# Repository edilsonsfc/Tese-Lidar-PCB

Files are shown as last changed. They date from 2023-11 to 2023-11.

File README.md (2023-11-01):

# Circuit Board (PCB) of Master's Thesis
This repository contains the circuit board project and supplementary materials related to my master's thesis.

## Table of Contents
- [Introduction](#introduction)
- [PCB](#pcb)
- [How to Use](#how-to-use)
- [Citation](#citation)

## Introduction
My master's thesis, titled "Three-dimensional mapping of an unknown environment based on a 2D laser measurement" explores the development of a low-cost 3D mapping system capable of generating a point cloud of an indoor environment and performing path planning. The work presented in this repository supports the findings and experiments conducted during the research process.
- [Hardware Structure](https://github.com/edilsonsfc/Tese-Lidar-Structure)
- [Printed Circuit Board](https://github.com/edilsonsfc/Tese-Lidar-PCB)
- [Control and Data Processing Algorithm](https://github.com/edilsonsfc/Tese-Lidar-Code)
- [Graphical User Interface](https://github.com/edilsonsfc/Tese-Lidar-GUI)

## PCB
This repository contains a collection of [...].

## How to Use

Feel free to explore and incorporate these models into your research or projects. Don't forget to cite this repository if you use the 3D models in your work.

## Citation
If you use the any material from this repository in your research or projects, please cite my master's thesis and this repository as follows:

- Master's Thesis: Ferreira, E. "Three-dimensional mapping of an unknown environment based on a 2D laser measurement" Instituto Politécnico de Bragança, 2023.
- Repository: https://github.com/edilsonsfc/Tese-Lidar-PCB

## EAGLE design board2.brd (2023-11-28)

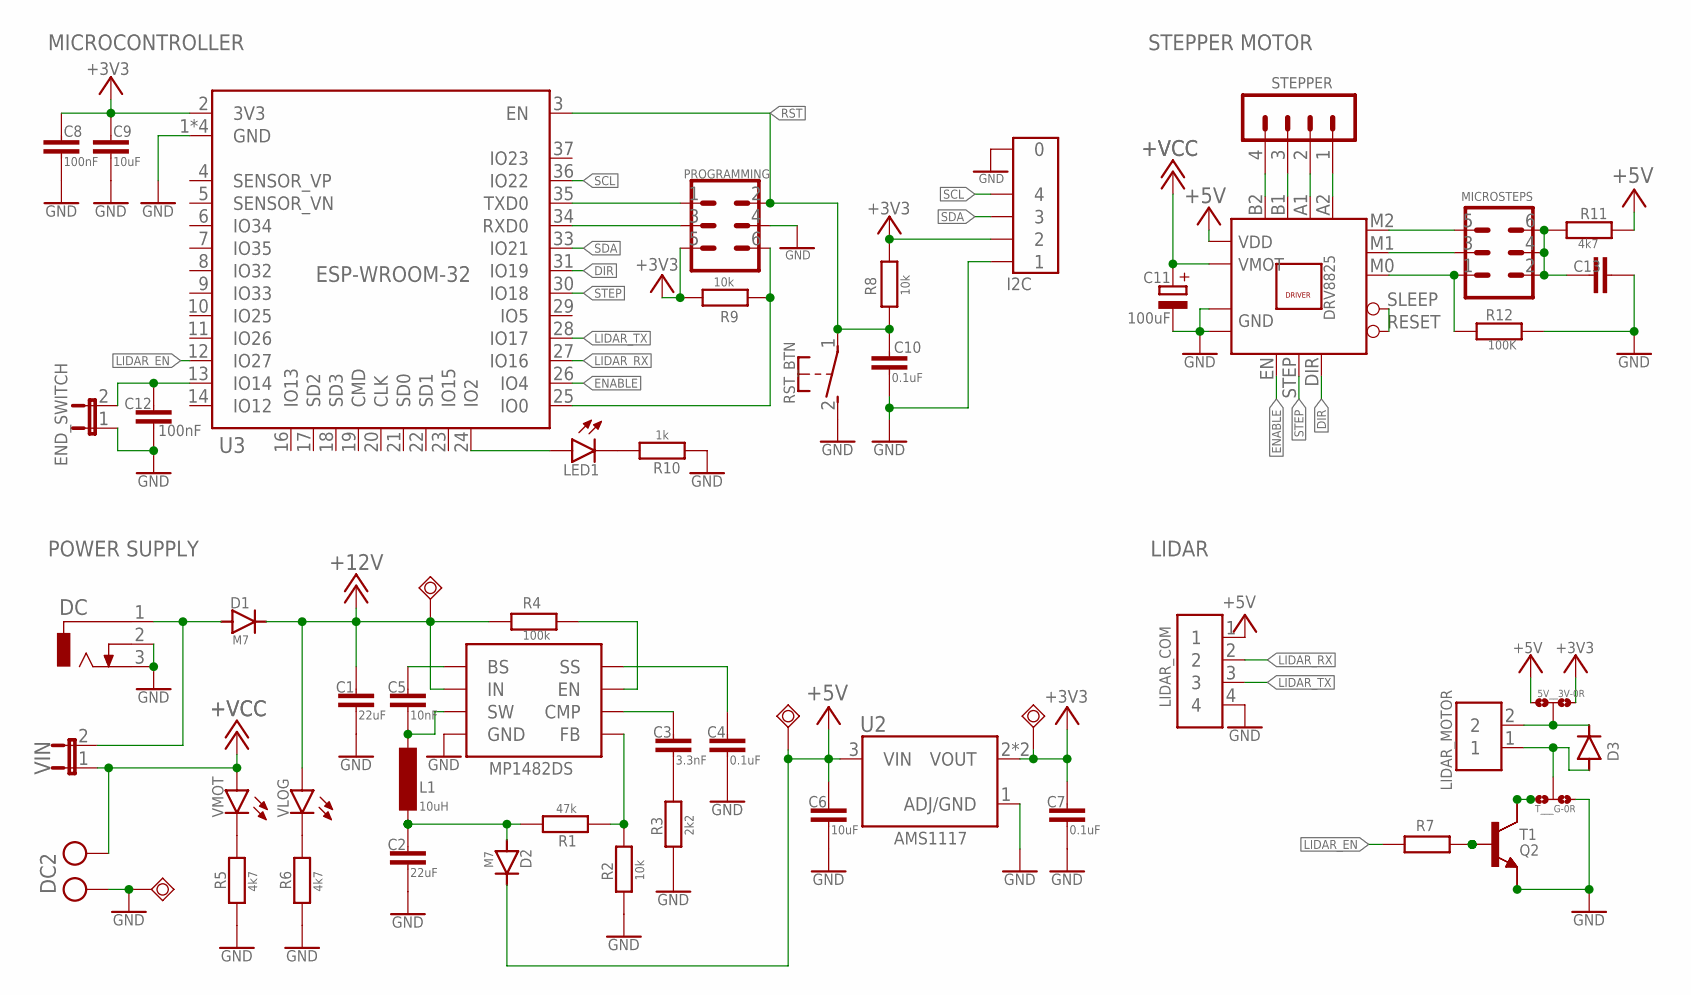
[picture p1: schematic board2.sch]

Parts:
3V3, 5V, 12V: TPSQTP07R; TP07R
5V__3V: 0R-JUMPA; A0R-JMP
C1, C2: 22uF; C1210K
C3: 3.3nF; C0805K
C4, C10: 0.1uF; C0805K
C5: 10nF; C0805K
C6, C9: 10uF; C1210K
C7: 0.1uF; C1210K
C8, C12: 100nF; C0805K
C11: 100uF; E3,5-8
C13: C-EUC0805K; C0805K
D1, D2, D3: M7; DO-214AC
DC: DCJ0202
DC2: DC2; AK500/2-H
DRIVER: DRV8825_PCB
DRV8825: DRV8825_H
END_SWITCH: END_SWITCH; JP1
GND: TPSQTP07R; TP07R
I2C: SM04B-SRSS-TB(LF)(SN); JST_SM04B-SRSS-TB(LF)(SN)
L1: 10uH; L5650M
LED1: 0; CHIP-LED0805
LIDAR_COM: 4PIN; B4B-PH-K-S
LIDAR_MOTOR: 2PIN; B2B-PH-K-S
MICROSTEPS: MicroSteps; MA03-2
PROGRAMMING: Programming; MA03-2
Q2: BC846ALT1SMD; SOT23
R1: 47k; R0805W
R2, R8, R9: 10k; R0805W
R3: 2k2; R0805W
R4: 100k; R0805W
R5, R6, R11: 4k7; R0805W
R7: R; R0805W
R10: 1k; R0805W
R12: 100K; R0805W
RST_BTN: DTSM-3
STEPPER: Stepper; MA04-1
T1: BD139_BCXXX; TO126+TO92
T___G: 0R-JUMPB; B0R-JMP
U1: MP1482DS; SOIC127P600X175-8N
U2: AMS1117; SOT229P700X180-4N
U3: ESP-WROOM-32
VIN: JUMPER; JP1
VLOG: 00; CHIP-LED0805
VMOT: 00; CHIP-LED0805

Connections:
+3V3: 3V3.TP, 5V__3V.1, 5V__3V.2, C7.1, C8.1, C9.1, D3.C, I2C.2, LIDAR_MOTOR.2, PROGRAMMING.5, R8.1, R9.2, U2.2 (VOUT), U2.4 (VOUT), U3.2 (3V3)
+5V: 5V.TP, 5V__3V.3, C6.2, D2.C, DRV8825.FAULT (VDD), LIDAR_COM.1, R11.2, U2.3 (VIN)
+12V: 12V.TP, C1.2, D1.C, R4.1, U1.2 (IN), VLOG.A
+VCC: C11.+, DC2.2, DRV8825.VMOT, DRV8825.VMOT1 (VMOT), VIN.1, VMOT.A
A1: DRV8825.A1, STEPPER.2
A2: DRV8825.A2, STEPPER.1
B1: DRV8825.B1, STEPPER.3
B2: DRV8825.B2, STEPPER.4
BS: C5.2, U1.1 (BS)
CMP: C3.2, U1.6 (CMP)
DIR: DRV8825.DIR, U3.31 (IO19)
EN: R4.2, U1.7 (EN)
ENABLE: DRV8825.EN, U3.26 (IO4)
END_SW: C12.2, END_SWITCH.2, U3.13 (IO14)
GND: C1.1, C2.2, C4.1, C6.1, C7.2, C8.2, C9.2, C10.2, C11.-, C12.1, C13.2, DC.2, DC.3, DC2.1, DRV8825.GND, DRV8825.GND1 (GMOT), END_SWITCH.1, GND.TP, I2C.1, I2C.S1 (0), I2C.S2 (0), LIDAR_COM.4, PROGRAMMING.4, Q2.2 (E), R2.1, R3.1, R5.1, R6.1, R10.1, R12.1, RST_BTN.2, T1.E, T1.E1 (E), T___G.3, U1.4 (GND), U2.1 (ADJ/GND), U3.1 (GND), U3.15 (GND), U3.38 (GND), U3.GND
IO0: PROGRAMMING.6, R9.1, U3.25 (IO0)
IO2: LED1.A, U3.24 (IO2)
LIDAR_EN: R7.1, U3.12 (IO27)
LIDAR_RX: LIDAR_COM.2, U3.27 (IO16)
LIDAR_TX: LIDAR_COM.3, U3.28 (IO17)
M0: DRV8825.M0, MICROSTEPS.1, R12.2
M1: DRV8825.M1, MICROSTEPS.3
M2: DRV8825.M2, MICROSTEPS.5
MT: D3.A, LIDAR_MOTOR.1, T___G.2
unnamed: C2.1, D2.A, L1.1, R1.1
unnamed: C3.1, R3.2
unnamed: R5.2, VMOT.C
unnamed: Q2.3 (C), T1.C, T___G.1
unnamed: C13.1, MICROSTEPS.2, MICROSTEPS.4, MICROSTEPS.6, R11.1
unnamed: LED1.C, R10.2
unnamed: R6.2, VLOG.C
unnamed: R1.2, R2.2, U1.5 (FB)
unnamed: DRV8825.RESET, DRV8825.SLEEP
unnamed: Q2.1 (B), R7.2, T1.B
RST: C10.1, PROGRAMMING.2, R8.2, RST_BTN.1, U3.3 (EN)
RXD: PROGRAMMING.3, U3.34 (RXD0)
SCL: I2C.4, U3.36 (IO22)
SDA: I2C.3, U3.33 (IO21)
SS: C4.2, U1.8 (SS)
STEP: DRV8825.STEP, U3.30 (IO18)
SW: C5.1, L1.2, U1.3 (SW)
TXD: PROGRAMMING.1, U3.35 (TXD0)
VIN: D1.A, DC.1, VIN.2

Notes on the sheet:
MICROCONTROLLER
STEPPER MOTOR
LIDAR
POWER SUPPLY

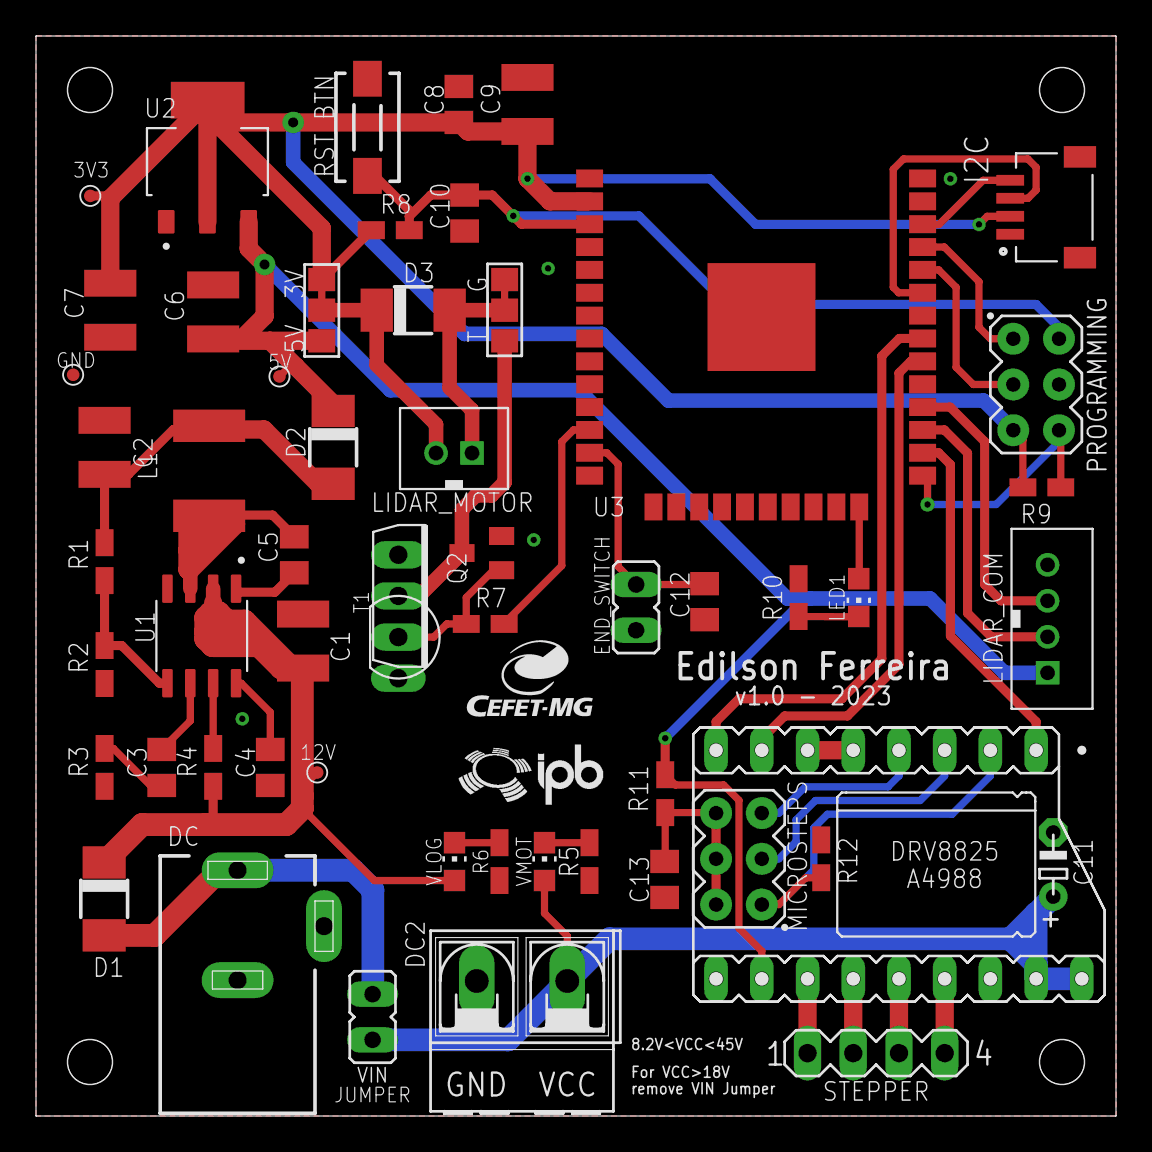
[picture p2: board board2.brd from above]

Board: 2 copper layers, 60.0 x 60.0 mm, 56 parts (0 on the bottom side), 43 nets.

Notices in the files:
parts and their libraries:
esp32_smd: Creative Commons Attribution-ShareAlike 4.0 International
